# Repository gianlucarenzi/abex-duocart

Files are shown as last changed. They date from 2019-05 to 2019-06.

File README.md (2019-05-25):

Atari DUO Cart for ABEX
=====================

This is a Atari Duo Cart board, designed for the Atari PBI & ECI Bus EXtender
or ABEX for short.

This Atari DUO Cart is a derivated work of the famous Uno-Cart Project

Rendered Images
===============
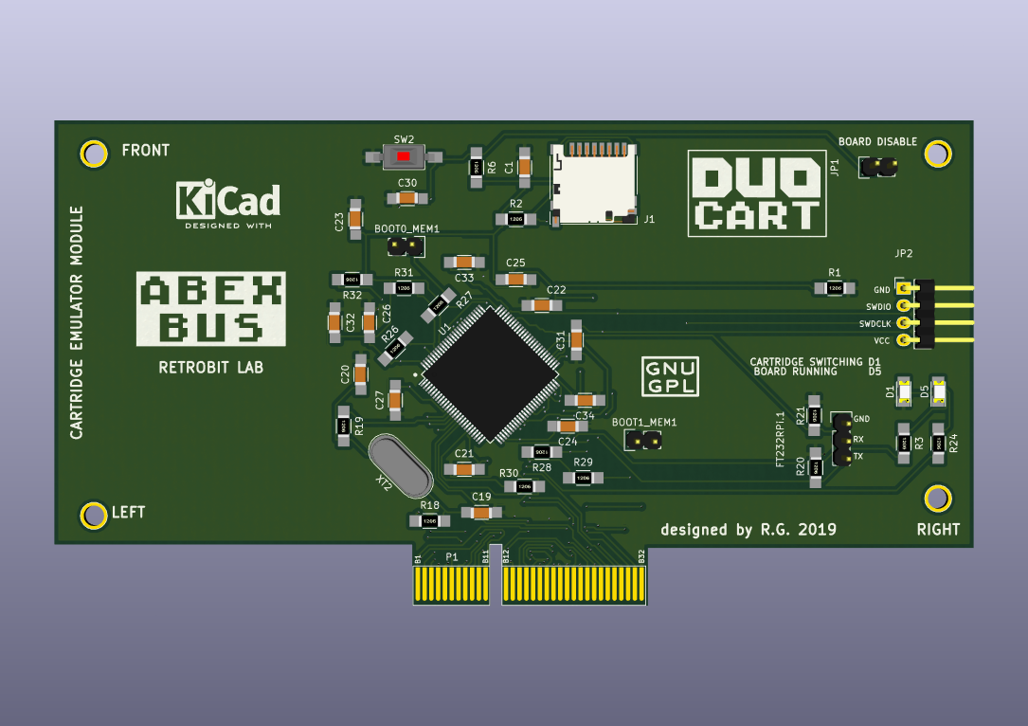
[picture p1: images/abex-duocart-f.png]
Board Front
# Front
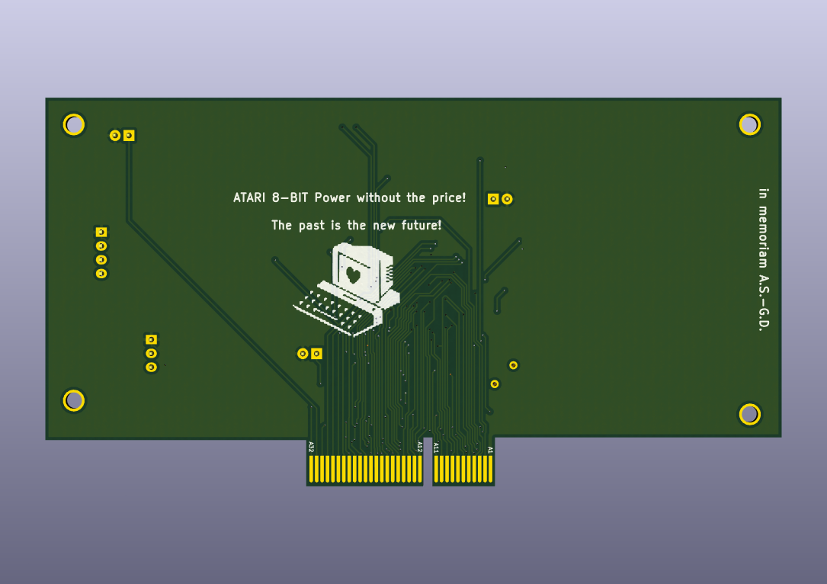
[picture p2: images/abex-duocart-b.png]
Board Back
# Back
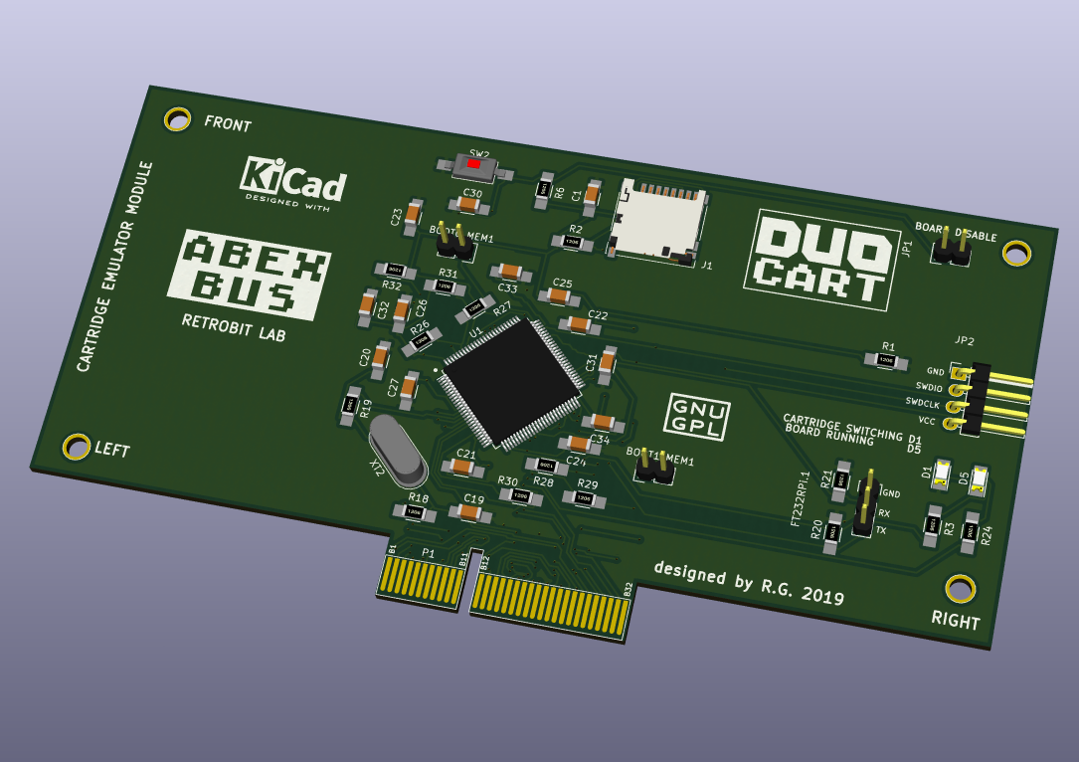
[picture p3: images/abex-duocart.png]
Board Overall
# Overall

Hardware License
================
Copyright (C) 2018/2019 Gianluca Renzi <gianlucarenzi@eurek.it> <icjtqr@gmail.com>

The hardware of this project is released as free/open hardware under the
Creative Commons Attribution Share-Alike license. See `LICENSE.hw` for details.

Firmware License
================
Copyright (C) 2019 Gianluca Renzi <icjtqr@gmail.com>

The microcontroller firmware of this project is released as free software,
under the terms of the GNU General Public License v3, or later.  See
`LICENSE.sw` for details.

Software License
================
The host software (amigafloppy tool) is released as free software, under the
terms of the GNU General Public License v3, or later. See `LICENSE.sw` or licence.txt for
details.

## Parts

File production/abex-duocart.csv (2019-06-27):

Id | Designator | Package | Quantity | Designation | Supplier and ref
1 | U1 | TQFP-100_14x14mm_Pitch0.5mm | 1 | STM32F407VGTx
2 | G*** | atari_800_XL_BW_25x25 | 1 | LOGO
3 | KICAD | KiCad-Logo2_6mm_SilkScreen | 1 | KiCad-Logo2_6mm_SilkScreen
4 | GPL | Symbol_GNU-GPL_SilkScreen_Small | 1 | Symbol_GNU-GPL_CopperTop_Small
5 | ATARI800XL | ABEX_Logo_22mmx11mm_WB | 1 | LOGO
6 | DUOCART | DUOCart_20x11_Rev | 1 | LOGO
7 | R24,R3 | R_1206_HandSoldering | 2 | 1.5K
8 | R2,R32,R31,R4,R5,R7 | R_1206_HandSoldering | 6 | 4.7K
9 | J1 | microSD_HC_Hirose_DM3D-SF | 1 | Micro_SD_Card_Det
10 | D5,D1 | LED_1206 | 2 | LED.GREEN
11 | C1,C31,C30,C27,C26,C25,C24,C23,C22,C21 | C_1206_HandSoldering | 10 | 100n
12 | P1 | BUS_PCIexpress_64pin | 1 | 0877159106
13 | XT2 | Crystal_HC49-4H_Vertical_3D | 1 | 8Mhz
14 | SW2 | SW_SPST_FSMSM_3D | 1 | SW_Push
15 | R30,R18,R1 | R_1206_HandSoldering | 3 | 0
16 | R29,R27 | R_1206_HandSoldering | 2 | 510
17 | R28,R26,R21,R20 | R_1206_HandSoldering | 4 | 10K
18 | R19 | R_1206_HandSoldering | 1 | 220
19 | R6 | R_1206_HandSoldering | 1 | 100K
20 | P5,P4,P3,P2 | MountingHole | 4 | CONN_01X01
21 | JP2 | Pin_Header_Angled_1x04 | 1 | CONN_01X04
22 | JP1,BOOT1_MEM1,BOOT0_MEM1 | Pin_Header_Straight_1x02 | 3 | CONN_01X02
23 | FT232RPi.1 | Pin_Header_Straight_1x03 | 1 | CONN_01X03
24 | C34,C33 | C_1206_HandSoldering | 2 | 2.2u
25 | C32 | C_1206_HandSoldering | 1 | 1u
26 | C20,C19 | C_1206_HandSoldering | 2 | 20p

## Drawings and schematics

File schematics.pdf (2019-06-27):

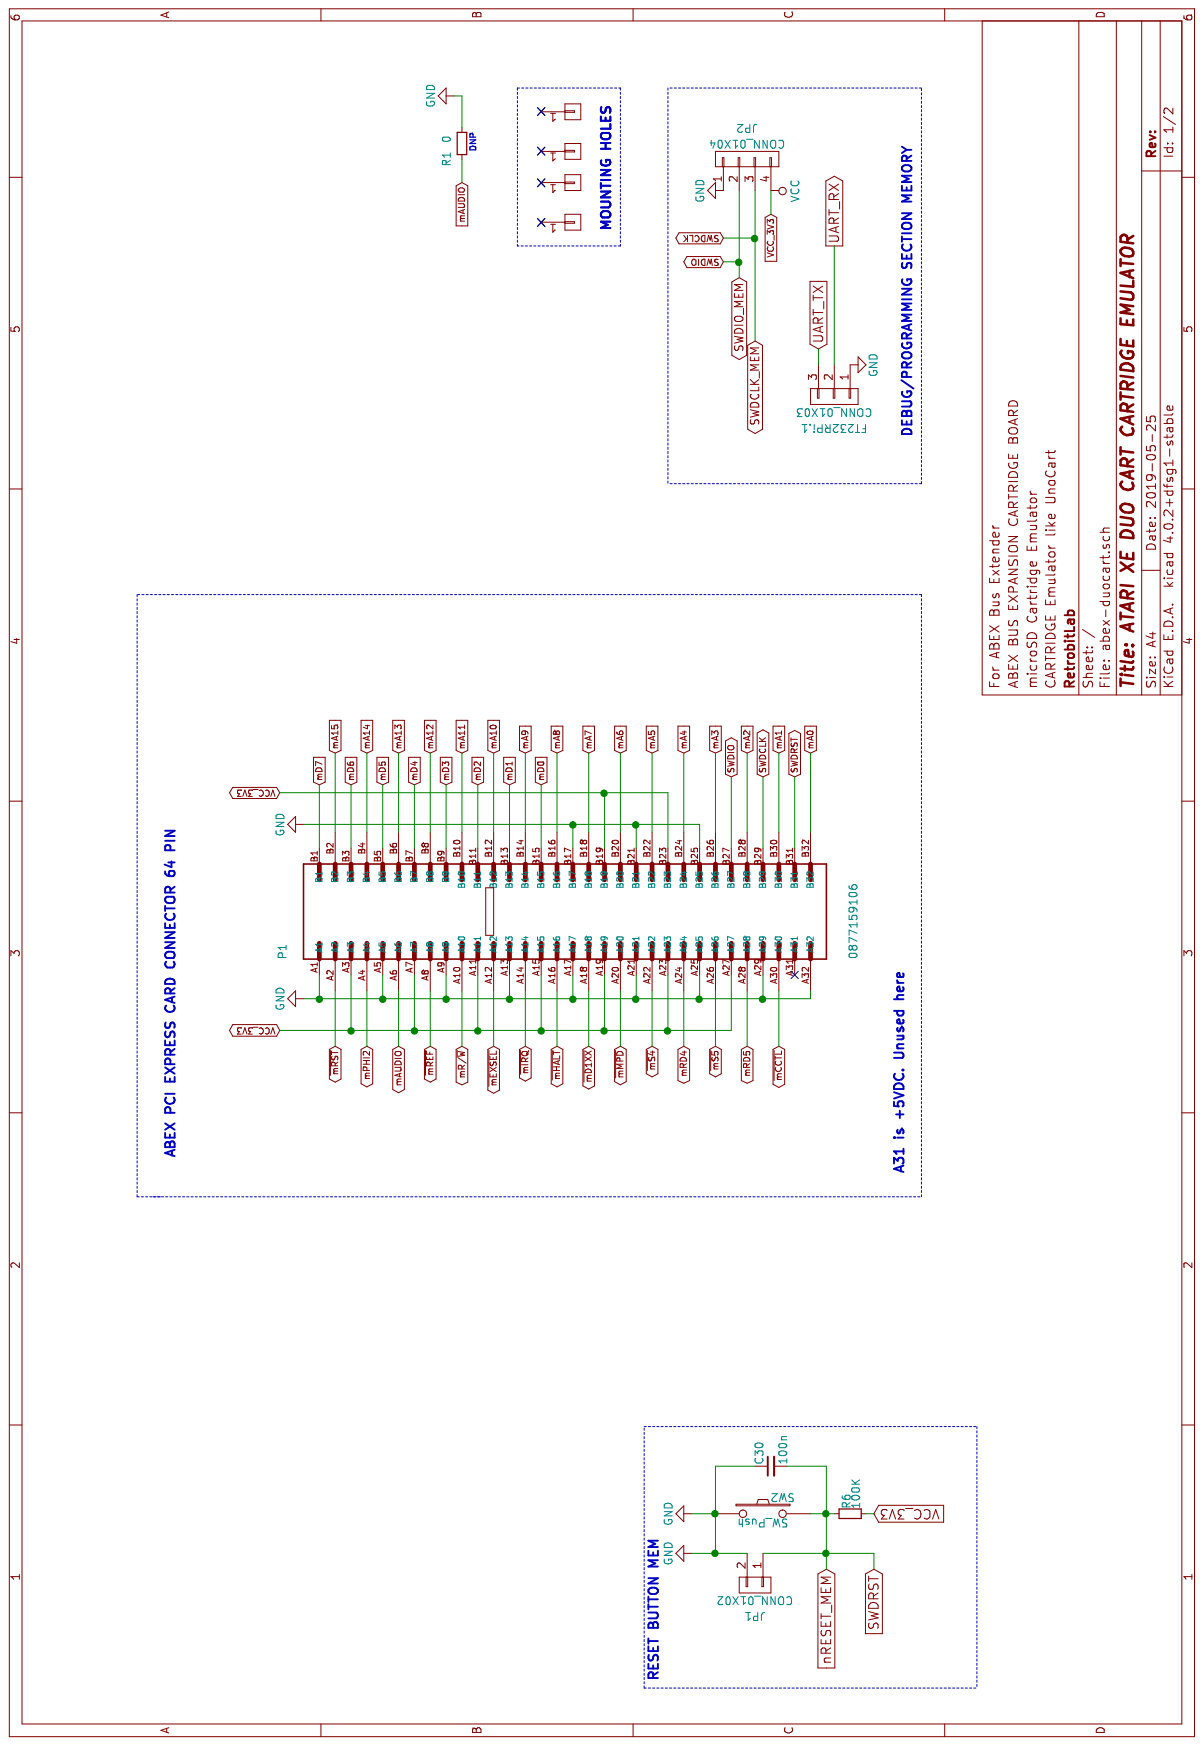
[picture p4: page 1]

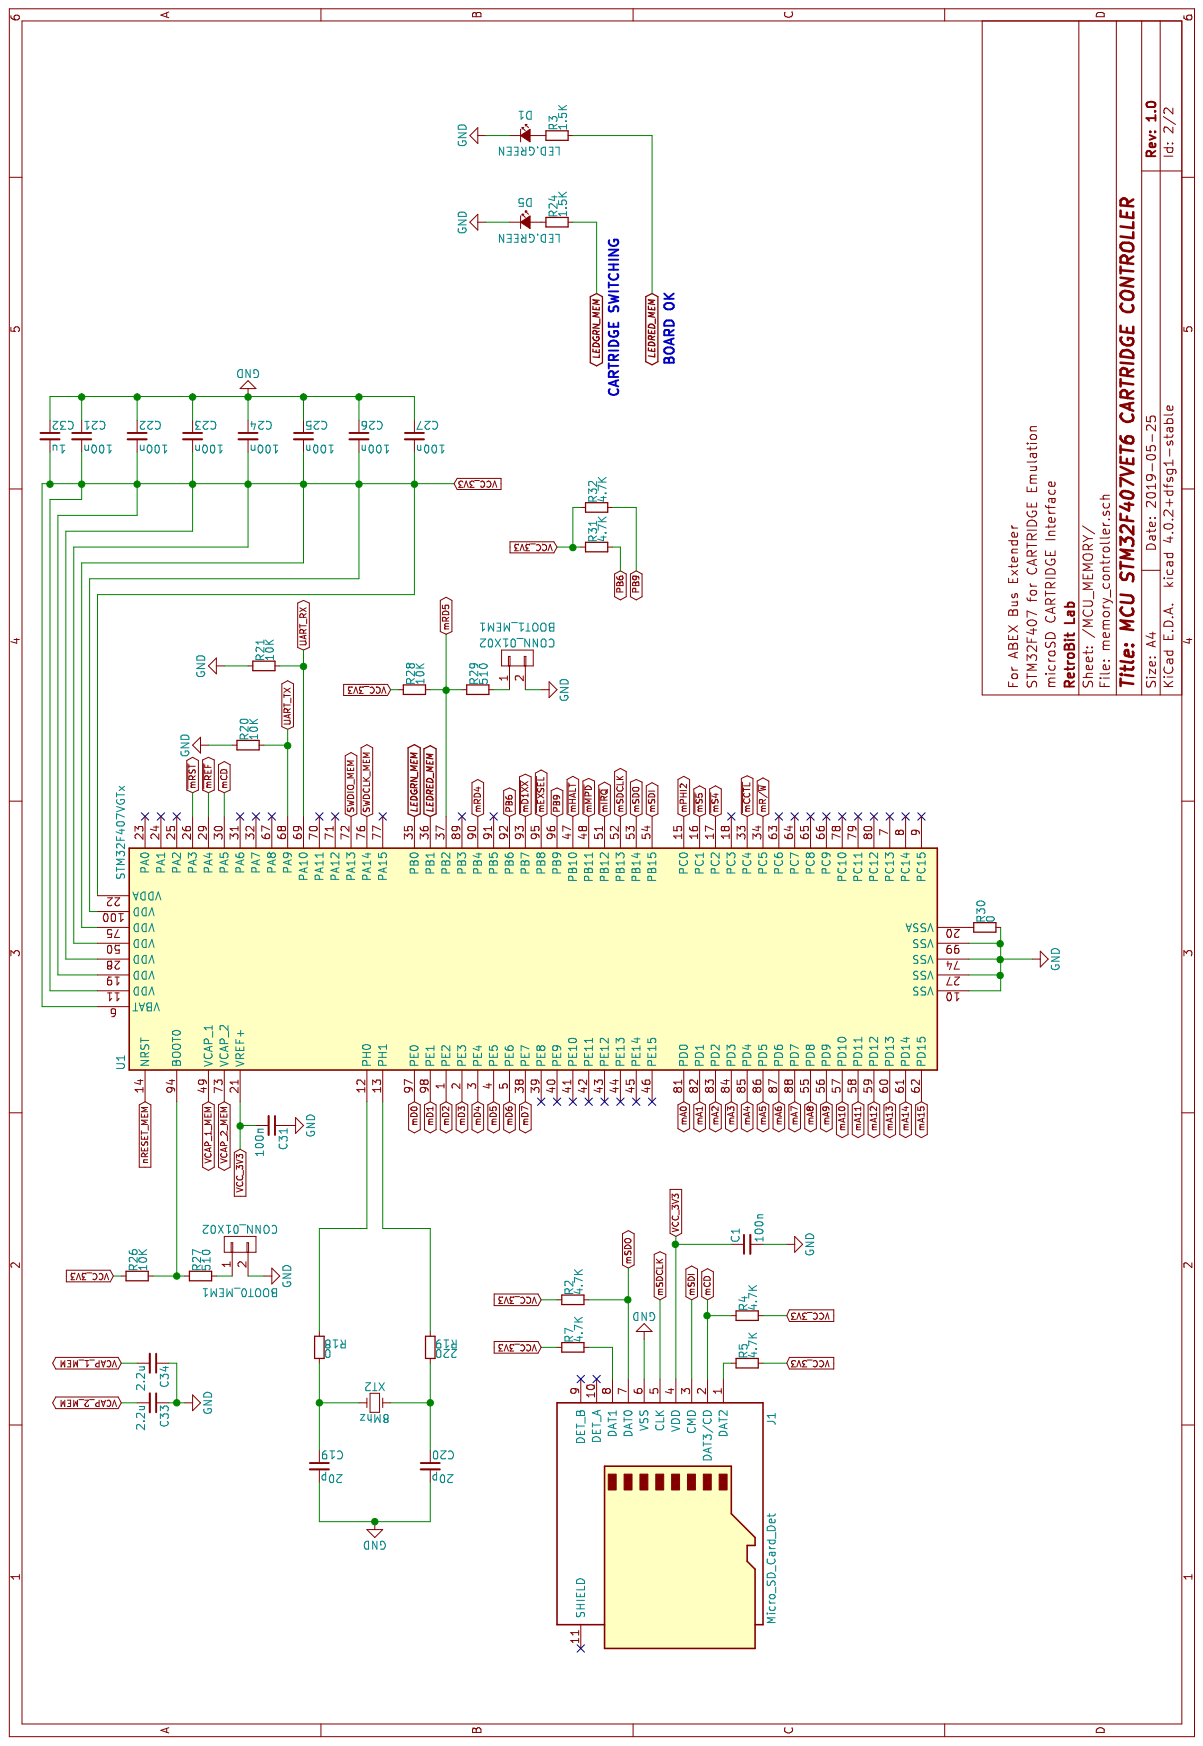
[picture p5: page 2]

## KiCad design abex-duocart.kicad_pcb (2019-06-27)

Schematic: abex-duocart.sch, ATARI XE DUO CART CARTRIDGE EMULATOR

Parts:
C30: 100n; C_1206_HandSoldering
FT232RPi.1: CONN_01X03; Pin_Header_Straight_1x03
JP1: CONN_01X02; Pin_Header_Straight_1x02
JP2: CONN_01X04; Pin_Header_Angled_1x04
P1: 0877159106; BUS_PCIexpress_64pin
P2, P3, P4, P5: CONN_01X01; MountingHole
R1: 0; R_1206_HandSoldering
R6: 100K; R_1206_HandSoldering
SW2: SW_Push; SW_SPST_FSMSM_3D

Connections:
GND: C30.1, FT232RPi.1.1, JP1.2, JP2.1, P1.A1, P1.A5, P1.A9, P1.A13, P1.A17, P1.A21, P1.A25, P1.A29, P1.A32, P1.B17, P1.B21, P1.B25, R1.2, SW2.1; also elsewhere on the board
SWDCLK: JP2.3, P1.B29; also elsewhere on the board
SWDIO: JP2.2, P1.B27; also elsewhere on the board
SWDRST: C30.2, JP1.1, P1.B31, R6.1, SW2.2; also elsewhere on the board
UART_RX: FT232RPi.1.2; also elsewhere on the board
UART_TX: FT232RPi.1.3; also elsewhere on the board
VCC_3V3: JP2.4, P1.A3, P1.A7, P1.A11, P1.A15, P1.A19, P1.A23, P1.A27, P1.B19, P1.B23, R6.2; also elsewhere on the board
mA0: P1.B32; also elsewhere on the board
mA1: P1.B30; also elsewhere on the board
mA2: P1.B28; also elsewhere on the board
mA3: P1.B26; also elsewhere on the board
mA4: P1.B24; also elsewhere on the board
mA5: P1.B22; also elsewhere on the board
mA6: P1.B20; also elsewhere on the board
mA7: P1.B18; also elsewhere on the board
mA8: P1.B16; also elsewhere on the board
mA9: P1.B14; also elsewhere on the board
mA10: P1.B12; also elsewhere on the board
mA11: P1.B10; also elsewhere on the board
mA12: P1.B8; also elsewhere on the board
mA13: P1.B6; also elsewhere on the board
mA14: P1.B4; also elsewhere on the board
mA15: P1.B2; also elsewhere on the board
mAUDIO: P1.A6, R1.1
mD0: P1.B15; also elsewhere on the board
mD1: P1.B13; also elsewhere on the board
mD2: P1.B11; also elsewhere on the board
mD3: P1.B9; also elsewhere on the board
mD4: P1.B7; also elsewhere on the board
mD5: P1.B5; also elsewhere on the board
mD6: P1.B3; also elsewhere on the board
mD7: P1.B1; also elsewhere on the board
mPHI2: P1.A4; also elsewhere on the board
mR/~W: P1.A10; also elsewhere on the board
mRD4: P1.A24; also elsewhere on the board
mRD5: P1.A28; also elsewhere on the board
~mCCTL: P1.A30; also elsewhere on the board
~mREF: P1.A8; also elsewhere on the board
~mRST: P1.A2; also elsewhere on the board
~mS4: P1.A22; also elsewhere on the board
~mS5: P1.A26; also elsewhere on the board

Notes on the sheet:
DEBUG/PROGRAMMING SECTION MEMORY
MOUNTING HOLES
RESET BUTTON MEM
DNP
ABEX PCI EXPRESS CARD CONNECTOR 64 PIN
A31 is +5VDC. Unused here

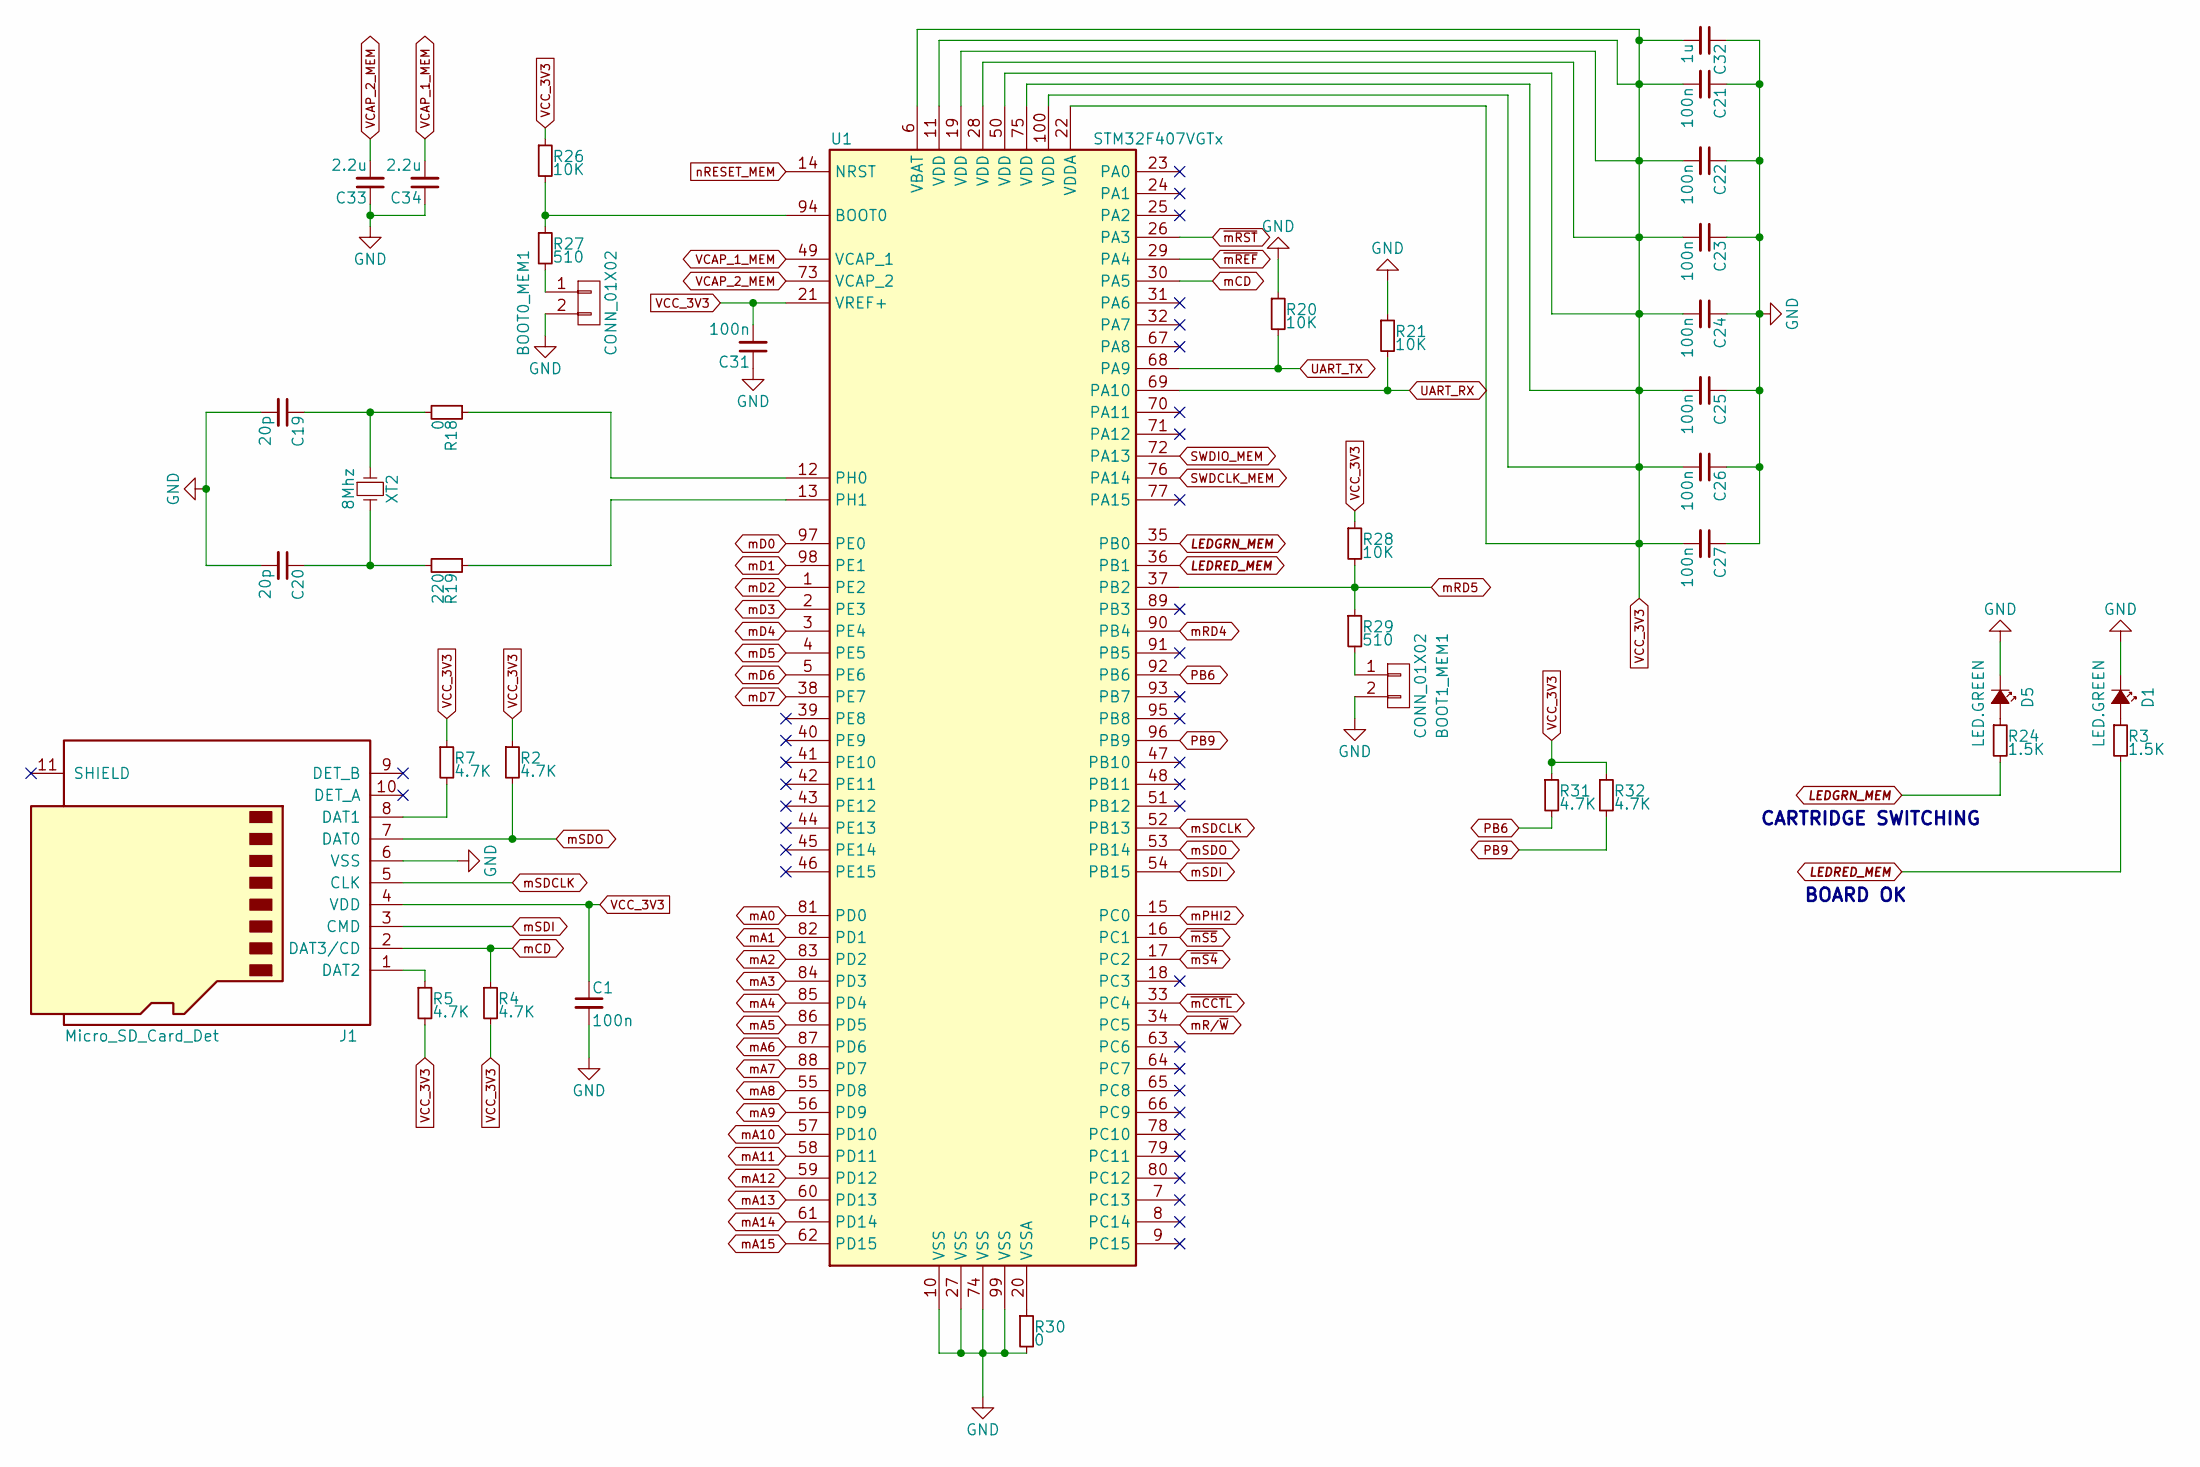
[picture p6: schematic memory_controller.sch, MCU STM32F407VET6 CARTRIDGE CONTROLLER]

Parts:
BOOT0_MEM1, BOOT1_MEM1: CONN_01X02; Pin_Header_Straight_1x02
C1, C21, C22, C23, C24, C25, C26, C27, C31: 100n; C_1206_HandSoldering
C19, C20: 20p; C_1206_HandSoldering
C32: 1u; C_1206_HandSoldering
C33, C34: 2.2u; C_1206_HandSoldering
D1, D5: LED.GREEN; LED_1206
J1: Micro_SD_Card_Det; microSD_HC_Hirose_DM3D-SF
R2, R4, R5, R7, R31, R32: 4.7K; R_1206_HandSoldering
R3, R24: 1.5K; R_1206_HandSoldering
R18, R30: 0; R_1206_HandSoldering
R19: 220; R_1206_HandSoldering
R20, R21, R26, R28: 10K; R_1206_HandSoldering
R27, R29: 510; R_1206_HandSoldering
U1: STM32F407VGTx; TQFP-100_14x14mm_Pitch0.5mm
XT2: 8Mhz; Crystal_HC49-4H_Vertical_3D

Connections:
GND: BOOT0_MEM1.2, BOOT1_MEM1.2, C1.2, C19.2, C20.2, C21.1, C22.1, C23.1, C24.1, C25.1, C26.1, C27.1, C31.1, C32.1, C33.1, C34.1, D1.1 (K), D5.1 (K), J1.6 (VSS), R20.1, R21.1, R30.2, U1.10 (VSS), U1.27 (VSS), U1.74 (VSS), U1.99 (VSS); also elsewhere on the board
LEDGRN_MEM: R24.2, U1.35 (PB0)
LEDRED_MEM: R3.2, U1.36 (PB1)
unnamed: BOOT0_MEM1.1, R27.2
unnamed: BOOT1_MEM1.1, R29.2
unnamed: C19.1, R18.2, XT2.1
unnamed: C20.1, R19.2, XT2.2
unnamed: D1.2 (A), R3.1
unnamed: D5.2 (A), R24.1
unnamed: J1.1 (DAT2), R5.1
unnamed: J1.8 (DAT1), R7.2
unnamed: R18.1, U1.12 (PH0)
unnamed: R19.1, U1.13 (PH1)
unnamed: R26.2, R27.1, U1.94 (BOOT0)
unnamed: R30.1, U1.20 (VSSA)
PB6: R31.2, U1.92 (PB6)
PB9: R32.2, U1.96 (PB9)
SWDCLK: U1.76 (PA14); also elsewhere on the board
SWDIO: U1.72 (PA13); also elsewhere on the board
SWDRST: U1.14 (NRST); also elsewhere on the board
UART_RX: R21.2, U1.69 (PA10); also elsewhere on the board
UART_TX: R20.2, U1.68 (PA9); also elsewhere on the board
VCAP_1_MEM: C34.2, U1.49 (VCAP_1)
VCAP_2_MEM: C33.2, U1.73 (VCAP_2)
VCC_3V3: C1.1, C21.2, C22.2, C23.2, C24.2, C25.2, C26.2, C27.2, C31.2, C32.2, J1.4 (VDD), R2.1, R4.2, R5.2, R7.1, R26.1, R28.1, R31.1, R32.1, U1.6 (VBAT), U1.11 (VDD), U1.19 (VDD), U1.21 (VREF+), U1.22 (VDDA), U1.28 (VDD), U1.50 (VDD), U1.75 (VDD), U1.100 (VDD); also elsewhere on the board
mA0: U1.81 (PD0); also elsewhere on the board
mA1: U1.82 (PD1); also elsewhere on the board
mA2: U1.83 (PD2); also elsewhere on the board
mA3: U1.84 (PD3); also elsewhere on the board
mA4: U1.85 (PD4); also elsewhere on the board
mA5: U1.86 (PD5); also elsewhere on the board
mA6: U1.87 (PD6); also elsewhere on the board
mA7: U1.88 (PD7); also elsewhere on the board
mA8: U1.55 (PD8); also elsewhere on the board
mA9: U1.56 (PD9); also elsewhere on the board
mA10: U1.57 (PD10); also elsewhere on the board
mA11: U1.58 (PD11); also elsewhere on the board
mA12: U1.59 (PD12); also elsewhere on the board
mA13: U1.60 (PD13); also elsewhere on the board
mA14: U1.61 (PD14); also elsewhere on the board
mA15: U1.62 (PD15); also elsewhere on the board
mCD: J1.2 (DAT3/CD), R4.1, U1.30 (PA5)
mD0: U1.97 (PE0); also elsewhere on the board
mD1: U1.98 (PE1); also elsewhere on the board
mD2: U1.1 (PE2); also elsewhere on the board
mD3: U1.2 (PE3); also elsewhere on the board
mD4: U1.3 (PE4); also elsewhere on the board
mD5: U1.4 (PE5); also elsewhere on the board
mD6: U1.5 (PE6); also elsewhere on the board
mD7: U1.38 (PE7); also elsewhere on the board
mPHI2: U1.15 (PC0); also elsewhere on the board
mR/~W: U1.34 (PC5); also elsewhere on the board
mRD4: U1.90 (PB4); also elsewhere on the board
mRD5: R28.2, R29.1, U1.37 (PB2); also elsewhere on the board
mSDCLK: J1.5 (CLK), U1.52 (PB13)
mSDI: J1.3 (CMD), U1.54 (PB15)
mSDO: J1.7 (DAT0), R2.2, U1.53 (PB14)
~mCCTL: U1.33 (PC4); also elsewhere on the board
~mREF: U1.29 (PA4); also elsewhere on the board
~mRST: U1.26 (PA3); also elsewhere on the board
~mS4: U1.17 (PC2); also elsewhere on the board
~mS5: U1.16 (PC1); also elsewhere on the board

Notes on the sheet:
CARTRIDGE SWITCHING
BOARD OK

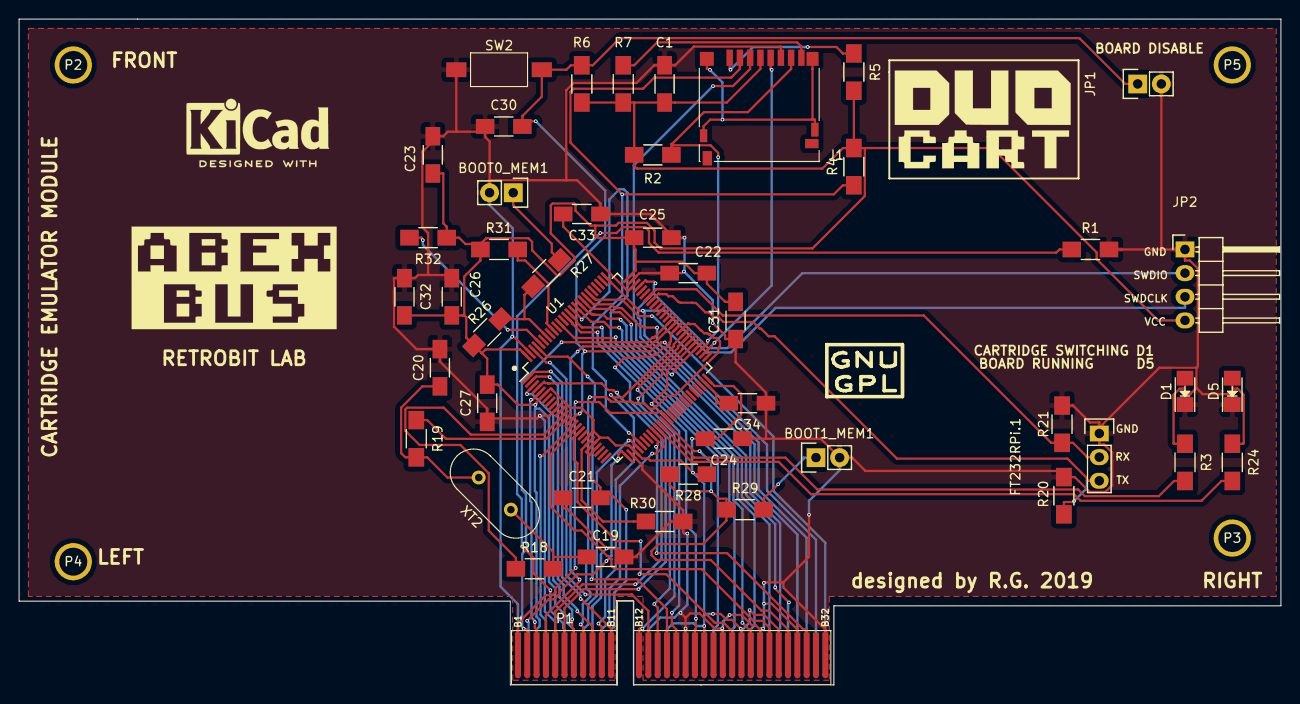
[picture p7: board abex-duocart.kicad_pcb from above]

Board: 2 copper layers, 135.5 x 71.5 mm, 54 parts (0 on the bottom side), 63 nets.

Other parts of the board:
ATARI800XL: LOGO; ABEX_Logo_22mmx11mm_WB
DUOCART: LOGO; DUOCart_20x11_Rev
GPL: Symbol_GNU-GPL_CopperTop_Small; Symbol_GNU-GPL_SilkScreen_Small
KICAD: KiCad-Logo2_6mm_SilkScreen

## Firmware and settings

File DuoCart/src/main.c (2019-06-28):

/*
 * ---------------------------------------
 * DUOCart Firmware (c)2019 Gianluca Renzi
 *
 * based on the original work by:
 *
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
 * You should have received a copy of the GNU General Public License
 * along with this program.  If not, see <http://www.gnu.org/licenses/>.
 */

#define _GNU_SOURCE

#include "defines.h"
#include "stm32f4xx.h"
#include "tm_stm32f4_fatfs.h"
#include "tm_stm32f4_delay.h"
#include <stdio.h>
#include <string.h>

#include "rom.h" /* unsigned char cart_rom[64*1024] */
#include "osrom.h"

#ifdef STM32F407xE
	#define stricmp strcasecmp
	#define strnicmp strncasecmp
#endif

static unsigned char cart_ram1[64*1024];
static unsigned char cart_ram2[64*1024] __attribute__((section(".ccmram")));
static unsigned char cart_d5xx[256] = {0};
static char errorBuf[40];

#define CART_CMD_OPEN_ITEM          0x00
#define CART_CMD_READ_CUR_DIR       0x01
#define CART_CMD_GET_DIR_ENTRY      0x02
#define CART_CMD_UP_DIR             0x03
#define CART_CMD_ROOT_DIR           0x04
#define CART_CMD_SEARCH             0x05
#define CART_CMD_LOAD_SOFT_OS       0x10
#define CART_CMD_SOFT_OS_CHUNK      0x11
#define CART_CMD_MOUNT_ATR          0x20    // unused, done automatically by firmware
#define CART_CMD_READ_ATR_SECTOR    0x21
#define CART_CMD_WRITE_ATR_SECTOR   0x22
#define CART_CMD_ATR_HEADER         0x23
#define CART_CMD_NO_CART            0xFE
#define CART_CMD_ACTIVATE_CART      0xFF

#define CART_TYPE_NONE              0
#define CART_TYPE_8K                1   // 8k
#define CART_TYPE_16K               2   // 16k
#define CART_TYPE_XEGS_32K          3   // 32k
#define CART_TYPE_XEGS_64K          4   // 64k
#define CART_TYPE_XEGS_128K         5   // 128k
#define CART_TYPE_SW_XEGS_32K       6   // 32k
#define CART_TYPE_SW_XEGS_64K       7   // 64k
#define CART_TYPE_SW_XEGS_128K      8   // 128k
#define CART_TYPE_MEGACART_16K      9   // 16k
#define CART_TYPE_MEGACART_32K      10  // 32k
#define CART_TYPE_MEGACART_64K      11  // 64k
#define CART_TYPE_MEGACART_128K     12  // 128k
#define CART_TYPE_BOUNTY_BOB        13  // 40k
#define CART_TYPE_ATARIMAX_1MBIT    14  // 128k
#define CART_TYPE_WILLIAMS_64K      15  // 32k/64k
#define CART_TYPE_OSS_16K_TYPE_B    16  // 16k
#define CART_TYPE_OSS_8K            17  // 8k
#define CART_TYPE_OSS_16K_034M      18  // 16k
#define CART_TYPE_OSS_16K_043M      19  // 16k
#define CART_TYPE_SIC_128K          20  // 128k
#define CART_TYPE_SDX_64K           21  // 64k
#define CART_TYPE_SDX_128K          22  // 128k
#define CART_TYPE_DIAMOND_64K       23  // 64k
#define CART_TYPE_EXPRESS_64K       24  // 64k
#define CART_TYPE_BLIZZARD_16K      25  // 16k
#define CART_TYPE_ATR               254
#define CART_TYPE_XEX               255

typedef struct {
	char isDir;
	char filename[13];
	char long_filename[32];
	char full_path[210];
} DIR_ENTRY;    // 256 bytes = 256 entries in 64k

static int num_dir_entries = 0; // how many entries in the current directory

static int entry_compare(const void* p1, const void* p2)
{
	DIR_ENTRY* e1 = (DIR_ENTRY*)p1;
	DIR_ENTRY* e2 = (DIR_ENTRY*)p2;
	if (e1->isDir && !e2->isDir)
		return -1;
	else
	if (!e1->isDir && e2->isDir)
		return 1;
	else
		return stricmp(e1->long_filename, e2->long_filename);
}

static char *get_filename_ext(char *filename)
{
	char *dot = strrchr(filename, '.');
	if(!dot || dot == filename)
		return "";
	return dot + 1;
}

static int is_valid_file(char *filename)
{
	char *ext = get_filename_ext(filename);
	if (stricmp(ext, "CAR") == 0 || stricmp(ext, "ROM") == 0
			|| stricmp(ext, "XEX") == 0 || stricmp(ext, "ATR") == 0)
		return 1;
	return 0;
}

// single FILINFO structure
static FILINFO fno;
static char lfn[_MAX_LFN + 1];   /* Buffer to store the LFN */

static void init()
{
	// this seems to be required for this version of FAT FS
	fno.lfname = lfn;
	fno.lfsize = sizeof lfn;
}

static int scan_files(char *path, char *search)
{
	FRESULT res;
	DIR dir;
	UINT i;

	res = f_opendir(&dir, path);
	if (res == FR_OK)
	{
		for (;;)
		{
			if (num_dir_entries == 255) break;
			res = f_readdir(&dir, &fno);
			if (res != FR_OK || fno.fname[0] == 0) break;
			if (fno.fattrib & (AM_HID | AM_SYS)) continue;
			if (fno.fattrib & AM_DIR)
			{
				i = strlen(path);
				strcat(path, "/");
				strcat(path, fno.fname);
				if (strlen(path) >= 210) continue;  // no more room for path in DIR_ENTRY
				res = scan_files(path, search);
				if (res != FR_OK) break;
				path[i] = 0;
			}
			else if (is_valid_file(fno.fname))
			{
				// copy the 8.3 filename to the LFN if blank
				if (!fno.lfname[0])
					strcpy(fno.lfname, fno.fname);
				char *match = strcasestr(fno.lfname, search);
				if (match)
				{
					DIR_ENTRY *dst = (DIR_ENTRY *)&cart_ram1[0];
					dst += num_dir_entries;
					// fill out a record
					dst->isDir = (match == fno.lfname) ? 1 : 0; // use this for a "score"
					strcpy(dst->filename, fno.fname);
					strncpy(dst->long_filename, fno.lfname, 31);
					dst->long_filename[31] = 0;
					// full path for search results
					strcpy(dst->full_path, path);
					num_dir_entries++;
				}
			}
		}
		f_closedir(&dir);
	}
	return res;
}

static int search_directory(char *path, char *search)
{
	char pathBuf[256];
	strcpy(pathBuf, path);
	num_dir_entries = 0;
	int i;
	FATFS FatFs;
	TM_DELAY_Init();
	if (f_mount(&FatFs, "", 1) == FR_OK)
	{
		if (scan_files(pathBuf, search) == FR_OK)
		{
			// sort by score, name
			qsort((DIR_ENTRY *)&cart_ram1[0], num_dir_entries, sizeof(DIR_ENTRY), entry_compare);
			DIR_ENTRY *dst = (DIR_ENTRY *)&cart_ram1[0];
			// reset the "scores" back to 0
			for (i=0; i<num_dir_entries; i++)
				dst[i].isDir = 0;
			return 1;
		}
	}
	strcpy(errorBuf, "Problem searching SD card");
	return 0;
}

static int read_directory(char *path)
{
	int ret = 0;
	num_dir_entries = 0;
	DIR_ENTRY *dst = (DIR_ENTRY *)&cart_ram1[0];

	FATFS FatFs;
	TM_DELAY_Init();
	if (f_mount(&FatFs, "", 1) == FR_OK)
	{
		DIR dir;
		if (f_opendir(&dir, path) == FR_OK)
		{
			while (num_dir_entries < 255)
			{
				if (f_readdir(&dir, &fno) != FR_OK || fno.fname[0] == 0)
					break;
				if (fno.fattrib & (AM_HID | AM_SYS))
					continue;
				dst->isDir = fno.fattrib & AM_DIR ? 1 : 0;
				if (!dst->isDir)
				{
					if (!is_valid_file(fno.fname))
						continue;
				}
				// copy file record to first ram block
				strcpy(dst->filename, fno.fname);
				if (fno.lfname[0])
				{
					strncpy(dst->long_filename, fno.lfname, 31);
					dst->long_filename[31] = 0;
				}
				else
				{
					strcpy(dst->long_filename, fno.fname);
				}
				dst->full_path[0] = 0; // path only for search results
				dst++;
				num_dir_entries++;
			}
			f_closedir(&dir);
		}
		else
		{
			strcpy(errorBuf, "Can't read directory");
		}
		f_mount(0, "", 1);
		qsort((DIR_ENTRY *)&cart_ram1[0], num_dir_entries, sizeof(DIR_ENTRY), entry_compare);
		ret = 1;
	}
	else
	{
		strcpy(errorBuf, "Can't read SD card");
	}
	return ret;
}

/* ATR Handling */

// ATR format
#define ATR_HEADER_SIZE 16
#define ATR_SIGNATURE 0x0296
typedef struct {
	uint16_t signature;
	uint16_t pars;
	uint16_t secSize;
	uint16_t parsHigh;
	uint8_t flags;
	uint16_t protInfo;
	uint8_t unused[5];
} ATRHeader;

typedef struct {
	char path[256];
	ATRHeader atrHeader;
	int filesize;
	FIL fil;
} MountedATR;

static MountedATR mountedATRs[1] = {0};

static FATFS FatFs;
static int doneFatFsInit = 0;

static int mount_atr(char *filename)
{
	// returns 0 for success or error code
	// 1 = no media, 2 = no file, 3 = bad atr
	if (!doneFatFsInit)
	{
		if (f_mount(&FatFs, "", 1) != FR_OK)
			return 1;
		doneFatFsInit = 1;
	}

	MountedATR *mountedATR = &mountedATRs[0];
	if (f_open(&mountedATR->fil, filename, FA_READ|FA_WRITE) != FR_OK)
		return 2;

	UINT br;
	if (f_read(&mountedATR->fil, &mountedATR->atrHeader, ATR_HEADER_SIZE, &br) != FR_OK ||
		br != ATR_HEADER_SIZE || mountedATR->atrHeader.signature != ATR_SIGNATURE)
	{
		f_close(&mountedATR->fil);
		return 3;
	}
	// success
	strcpy(mountedATR->path, filename);
	mountedATR->filesize = f_size(&mountedATR->fil);
	return 0;
}

static int read_atr_sector(uint16_t sector, uint8_t page, uint8_t *buf)
{
	// returns 0 for success or error code
	// 1 = no ATR mounted, 2 = invalid sector
	MountedATR *mountedATR = &mountedATRs[0];

	if (!mountedATR->path[0])
		return 1;

	if (sector == 0)
		return 2;

	int offset = ATR_HEADER_SIZE;
	// first 3 sectors are always 128 bytes
	if (sector <=3)
		offset += (sector - 1) * 128;
	else
		offset += (3 * 128) + ((sector - 4) * mountedATR->atrHeader.secSize) + (page * 128);

	// check we're not reading beyond the end of the file..
	if (offset > (mountedATR->filesize - 128))
	{
		memset(buf, 0 , 128);   // return blank sector?
		return 0;
	}

	UINT br;
	if (f_lseek(&mountedATR->fil, offset) != FR_OK ||
		f_read(&mountedATR->fil, buf, 128, &br) != FR_OK || br != 128)
		return 2;
	return 0;
}

static int write_atr_sector(uint16_t sector, uint8_t page, uint8_t *buf)
{
	// returns 0 for success or error code
	// 1 = no ATR mounted, 2 = write error
	MountedATR *mountedATR = &mountedATRs[0];

	if (!mountedATR->path[0])
		return 1;

	if (sector == 0)
		return 2;

	int offset = ATR_HEADER_SIZE;
	// first 3 sectors are always 128 bytes
	if (sector <=3)
		offset += (sector - 1) * 128;
	else
		offset += (3 * 128) + ((sector - 4) * mountedATR->atrHeader.secSize) + (page * 128);

	// check we're not writing beyond the end of the file..
	if (offset > (mountedATR->filesize - 128))
		return 2;
	UINT bw;
	if (f_lseek(&mountedATR->fil, offset) != FR_OK ||
		f_write(&mountedATR->fil, buf, 128, &bw) != FR_OK ||
		f_sync(&mountedATR->fil) != FR_OK  || bw != 128)
		return 2;
	return 0;
}

/* CARTRIDGE/XEX HANDLING */

static int load_file(char *filename)
{
	TM_DELAY_Init();
	FATFS FatFs;
	int cart_type = CART_TYPE_NONE;
	int car_file = 0, xex_file = 0, expectedSize = 0;
	unsigned char carFileHeader[16];
	UINT br, size = 0;

	if (strncasecmp(filename+strlen(filename)-4, ".CAR", 4) == 0)
		car_file = 1;
	if (strncasecmp(filename+strlen(filename)-4, ".XEX", 4) == 0)
		xex_file = 1;

	if (f_mount(&FatFs, "", 1) != FR_OK)
	{
		strcpy(errorBuf, "Can't read SD card");
		return 0;
	}

	FIL fil;
	if (f_open(&fil, filename, FA_READ) != FR_OK)
	{
		strcpy(errorBuf, "Can't open file");
		goto cleanup;
	}

	// read the .CAR file header?
	if (car_file)
	{
		if (f_read(&fil, carFileHeader, 16, &br) != FR_OK || br != 16)
		{
			strcpy(errorBuf, "Bad CAR file");
			goto closefile;
		}

		int car_type = carFileHeader[7];
		if (car_type == 1)       { cart_type = CART_TYPE_8K;             expectedSize =   8192; }
		else if (car_type == 2)  { cart_type = CART_TYPE_16K;            expectedSize =  16384; }
		else if (car_type == 3)  { cart_type = CART_TYPE_OSS_16K_034M;   expectedSize =  16384; }
		else if (car_type == 8)  { cart_type = CART_TYPE_WILLIAMS_64K;   expectedSize =  65536; }
		else if (car_type == 9)  { cart_type = CART_TYPE_EXPRESS_64K;    expectedSize =  65536; }
		else if (car_type == 10) { cart_type = CART_TYPE_DIAMOND_64K;    expectedSize =  65536; }
		else if (car_type == 11) { cart_type = CART_TYPE_SDX_64K;        expectedSize =  65536; }
		else if (car_type == 12) { cart_type = CART_TYPE_XEGS_32K;       expectedSize =  32768; }
		else if (car_type == 13) { cart_type = CART_TYPE_XEGS_64K;       expectedSize =  65536; }
		else if (car_type == 14) { cart_type = CART_TYPE_XEGS_128K;      expectedSize = 131072; }
		else if (car_type == 15) { cart_type = CART_TYPE_OSS_16K_TYPE_B; expectedSize =  16384; }
		else if (car_type == 18) { cart_type = CART_TYPE_BOUNTY_BOB;     expectedSize =  40960; }
		else if (car_type == 22) { cart_type = CART_TYPE_WILLIAMS_64K;   expectedSize =  32768; }
		else if (car_type == 26) { cart_type = CART_TYPE_MEGACART_16K;   expectedSize =  16384; }
		else if (car_type == 27) { cart_type = CART_TYPE_MEGACART_32K;   expectedSize =  32768; }
		else if (car_type == 28) { cart_type = CART_TYPE_MEGACART_64K;   expectedSize =  65536; }
		else if (car_type == 29) { cart_type = CART_TYPE_MEGACART_128K;  expectedSize = 131072; }
		else if (car_type == 33) { cart_type = CART_TYPE_SW_XEGS_32K;    expectedSize =  32768; }
		else if (car_type == 34) { cart_type = CART_TYPE_SW_XEGS_64K;    expectedSize =  65536; }
		else if (car_type == 35) { cart_type = CART_TYPE_SW_XEGS_128K;   expectedSize = 131072; }
		else if (car_type == 40) { cart_type = CART_TYPE_BLIZZARD_16K;   expectedSize =  16384; }
		else if (car_type == 41) { cart_type = CART_TYPE_ATARIMAX_1MBIT; expectedSize = 131072; }
		else if (car_type == 43) { cart_type = CART_TYPE_SDX_128K;       expectedSize = 131072; }
		else if (car_type == 44) { cart_type = CART_TYPE_OSS_8K;         expectedSize =   8192; }
		else if (car_type == 45) { cart_type = CART_TYPE_OSS_16K_043M;   expectedSize =  16384; }
		else if (car_type == 54) { cart_type = CART_TYPE_SIC_128K;       expectedSize = 131072; }
		else
		{
			strcpy(errorBuf, "Unsupported CAR type");
			goto closefile;
		}
	}

	// set a default error
	strcpy(errorBuf, "Can't read file");

	unsigned char *dst = &cart_ram1[0];
	int bytes_to_read = 64 * 1024;
	if (xex_file)
	{
		dst += 4;   // leave room for the file length at the start of sram
		bytes_to_read -= 4;
	}

	// read the file in two 64k chunks to each area of SRAM
	if (f_read(&fil, dst, bytes_to_read, &br) != FR_OK)
	{
		cart_type = CART_TYPE_NONE;
		goto closefile;
	}
	size += br;

	if (br == bytes_to_read)
	{
		// first 64k was complete, so try to load 64k more
		if (f_read(&fil, &cart_ram2[0], 64*1024, &br) != FR_OK)
		{
			cart_type = CART_TYPE_NONE;
			goto closefile;
		}
		size += br;
		if (br == 64*1024)
		{
			// that's 128k read, is there any more?
			if (f_read(&fil, carFileHeader, 1, &br) != FR_OK)
			{
				cart_type = CART_TYPE_NONE;
				goto closefile;
			}
			if  (br == 1)
			{
				strcpy(errorBuf, "Cart file/XEX too big (>128k)");
				cart_type = CART_TYPE_NONE;
				goto closefile;
			}
		}
	}

	// set the correct cart type based on the size
	if (car_file)
	{
		if (size != expectedSize)
		{
			strcpy(errorBuf, "CAR file is wrong size");
			cart_type = CART_TYPE_NONE;
			goto closefile;
		}
	}
	else if (xex_file)
	{
		cart_type = CART_TYPE_XEX;
		// stick the size of the file as the first 4 bytes (little endian)
		cart_ram1[0] = size & 0xFF;
		cart_ram1[1] = (size >> 8) & 0xFF;
		cart_ram1[2] = (size >> 16) & 0xFF;
		cart_ram1[3] = 0;   // has to be zero!
	}
	else
	{
		// not a car/xex file - guess the type based on size
		if (size == 8*1024)        cart_type = CART_TYPE_8K;
		else if (size == 16*1024)  cart_type = CART_TYPE_16K;
		else if (size == 32*1024)  cart_type = CART_TYPE_XEGS_32K;
		else if (size == 64*1024)  cart_type = CART_TYPE_XEGS_64K;
		else if (size == 128*1024) cart_type = CART_TYPE_XEGS_128K;
		else
		{
			strcpy(errorBuf, "Unsupported ROM size ");
			cart_type = CART_TYPE_NONE;
			goto closefile;
		}
	}

closefile:
	f_close(&fil);
cleanup:
	f_mount(0, "", 1);
	return cart_type;
}

#define RD5_LOW      GPIOB->BSRRH = GPIO_Pin_2;
#define RD4_LOW      GPIOB->BSRRH = GPIO_Pin_4;
#define RD5_HIGH     GPIOB->BSRRL = GPIO_Pin_2;
#define RD4_HIGH     GPIOB->BSRRL = GPIO_Pin_4;

#define CONTROL_IN   GPIOC->IDR
#define ADDR_IN      GPIOD->IDR
#define DATA_IN      GPIOE->IDR
#define DATA_OUT     GPIOE->ODR

#define PHI2_RD          (GPIOC->IDR & 0x0001)
#define S5_RD            (GPIOC->IDR & 0x0002)
#define S4_RD            (GPIOC->IDR & 0x0004)
#define S4_AND_S5_HIGH   (GPIOC->IDR & 0x0006) == 0x6

#define PHI2    0x0001
#define S5      0x0002
#define S4      0x0004
#define CCTL    0x0010
#define RW      0x0020

#define SET_DATA_MODE_IN      GPIOE->MODER = 0x00000000;
#define SET_DATA_MODE_OUT     GPIOE->MODER = 0x00005555;

#define GREEN_LED_OFF         GPIOB->BSRRH = GPIO_Pin_0;
#define RED_LED_OFF           GPIOB->BSRRH = GPIO_Pin_1;
#define GREEN_LED_ON          GPIOB->BSRRL = GPIO_Pin_0;
#define RED_LED_ON            GPIOB->BSRRL = GPIO_Pin_1;

#define ATARI_RESET_ASSERT    GPIOA->BSRRL = GPIO_Pin_3; /* RST -> GPIO(A.3) LOW */
#define ATARI_RESET_DEASSERT  GPIOA->BSRRH = GPIO_Pin_3; /* RST -> GPIO(A.3) HIGH */

enum {
    INSERTED = 0,
    REMOVED,
};

/* Polling CARD_STATUS will returns any NON-ZERO value if there is
 * NO CARD in the microSD Slot, otherwise it will returns '0' if a card
 * is inserted.
 */
#define CARD_STATUS    (GPIOA->IDR & (1 << 5))

/*
 * ******************** DEBUG PORT UART *****************************
 */
#define DEBUG_TX           GPIO_Pin_9
#define DEBUG_RX           GPIO_Pin_10
#define DEBUG_PINSRC_TX    GPIO_PinSource9
#define DEBUG_PINSRC_RX    GPIO_PinSource10
#define DEBUG_PORT         GPIOA
enum {
	DBG_ERROR = 0,
	DBG_INFO,
	DBG_VERBOSE,
	DBG_NOISY,
};
static int debuglevel = DBG_INFO;
#define print(str)  USART_PutString(str)
/* ANSI Eye-Candy ;-) */
#define ANSI_RED    "\x1b[31m"
#define ANSI_GREEN  "\x1b[32m"
#define ANSI_YELLOW "\x1b[1;33m"
#define ANSI_BLUE   "\x1b[1;34m"
#define ANSI_RESET  "\x1b[0m"
#define DBG_E(str)  print(ANSI_RED); print(str); print(ANSI_RESET);
#define DBG_I(str)  if (debuglevel >= DBG_INFO)    { print(ANSI_GREEN);  print(str); print(ANSI_RESET); }
#define DBG_V(str)  if (debuglevel >= DBG_VERBOSE) { print(ANSI_BLUE);   print(str); print(ANSI_RESET); }
#define DBG_N(str)  if (debuglevel >= DBG_NOISY)   { print(ANSI_YELLOW); print(str); print(ANSI_RESET); }

GPIO_InitTypeDef  GPIO_InitStructure;
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
int main(void)
{
	/* Output: RESET & REF */
	config_gpio_others();

	ATARI_RESET_ASSERT

	config_uart(115200);

	banner();

	DBG_V("ATARI COMPUTER IN RESET MODE\r\n");

	/* Ouptut: LEDS - PB{0..1}, RD5 - PB2, RD4 - PB4 */
	config_gpio_leds_RD45();
	/* InOut: Data - PE{8..15} */
	config_gpio_data();
	/* In: Address - PD{0..15} */
	config_gpio_addr();
	/* In: Other Cart Input Sigs - PC{0..2, 4..5} */
	config_gpio_sig();

	RED_LED_ON
	int cartType = 0, atrMode = 0;
	char curPath[256] = "";
	char path[256];
	init();

	DBG_V("ATARI COMPUTER OUT OF RESET MODE\r\n");

	ATARI_RESET_DEASSERT

	while (1)
	{
		GREEN_LED_OFF

		int cmd = emulate_boot_rom(atrMode);

		GREEN_LED_ON

		// OPEN ITEM n
		if (cmd == CART_CMD_OPEN_ITEM)
		{
			int n = cart_d5xx[0x00];
			DIR_ENTRY *entry = (DIR_ENTRY *)&cart_ram1[0];
			if (entry[n].isDir)
			{
				// directory
				strcat(curPath, "/");
				strcat(curPath, entry[n].filename);
				cart_d5xx[0x01] = 0; // path changed
			}
			else
			{
				// file/search result
				if (entry[n].full_path[0])
					strcpy(path, entry[n].full_path);   // search result
				else
					strcpy(path, curPath); // file in current directory

				strcat(path, "/");
				strcat(path, entry[n].filename);
				if (stricmp(get_filename_ext(entry[n].filename), "ATR")==0)
				{
					// ATR
					cart_d5xx[0x01] = 3;    // ATR
					cartType = CART_TYPE_ATR;
				}
				else
				{
					// ROM,CAR or XEX
					cartType = load_file(path);
					if (cartType)
						cart_d5xx[0x01] = (cartType != CART_TYPE_XEX ? 1 : 2);  // file was loaded
					else
					{
						cart_d5xx[0x01] = 4;    // error
						strcpy((char*)&cart_d5xx[0x02], errorBuf);
					}
				}
			}
		}
		// READ DIR
		else
		if (cmd == CART_CMD_READ_CUR_DIR)
		{
			int ret = read_directory(curPath);
			if (ret)
			{
				cart_d5xx[0x01] = 0;    // ok
				cart_d5xx[0x02] = num_dir_entries;
			}
			else
			{
				cart_d5xx[0x01] = 1;    // error
				strcpy((char*)&cart_d5xx[0x02], errorBuf);
			}
		}
		// GET DIR ENTRY n
		else
		if (cmd == CART_CMD_GET_DIR_ENTRY)
		{
			int n = cart_d5xx[0x00];
			DIR_ENTRY *entry = (DIR_ENTRY *)&cart_ram1[0];
			cart_d5xx[0x01] = entry[n].isDir;
			strcpy((char*)&cart_d5xx[0x02], entry[n].long_filename);
		}
		// UP A DIRECTORY LEVEL
		else
		if (cmd == CART_CMD_UP_DIR)
		{
			int len = strlen(curPath);
			while (len && curPath[--len] != '/')
				;
			curPath[len] = 0;
		}
		// ROOT DIR (when atari reset pressed)
		else
		if (cmd == CART_CMD_ROOT_DIR)
			curPath[0] = 0;
		// SEARCH str
		else
		if (cmd == CART_CMD_SEARCH)
		{
			char searchStr[32];
			strcpy(searchStr, (char*)&cart_d5xx[0x00]);
			int ret = search_directory(curPath, searchStr);
			if (ret)
			{
				cart_d5xx[0x01] = 0;    // ok
				cart_d5xx[0x02] = num_dir_entries;
			}
			else
			{
				cart_d5xx[0x01] = 1;    // error
				strcpy((char*)&cart_d5xx[0x02], errorBuf);
			}
		}
		else
		if (cmd == CART_CMD_LOAD_SOFT_OS)
		{
			int ret = load_file("UNO_OS.ROM");
			if (!ret)
			{
				for (int i=0; i<16384; i++)
					cart_ram1[i] = os_rom[i];
			}
			cart_d5xx[0x01] = 0;    // ok
		}
		else
		if (cmd == CART_CMD_SOFT_OS_CHUNK)
		{
			int n = cart_d5xx[0x00];
			for (int i=0; i<128; i++)
				cart_d5xx[0x01+i]=cart_ram1[n*128+i];
		}
		else
		if (cmd == CART_CMD_READ_ATR_SECTOR)
		{
			//uint8_t device = cart_d5xx[0x00];
			uint16_t sector = (cart_d5xx[0x02] << 8) | cart_d5xx[0x01];
			uint8_t offset = cart_d5xx[0x03];   // 0 = first 128 byte "page", 1 = second, etc
			int ret = read_atr_sector(sector, offset, &cart_d5xx[0x02]);
			cart_d5xx[0x01] = ret;
		}
		else
		if (cmd == CART_CMD_WRITE_ATR_SECTOR)
		{
			//uint8_t device = cart_d5xx[0x00];
			GREEN_LED_OFF
			RED_LED_ON
			uint16_t sector = (cart_d5xx[0x02] << 8) | cart_d5xx[0x01];
			uint8_t offset = cart_d5xx[0x03];   // 0 = first 128 byte "page", 1 = second, etc
			int ret = write_atr_sector(sector, offset, &cart_d5xx[0x04]);
			cart_d5xx[0x01] = ret;
			RED_LED_OFF
		}
		else
		if (cmd == CART_CMD_ATR_HEADER)
		{
			//uint8_t device = cart_d5xx[0x00];
			if (!&mountedATRs[0].path[0])
				cart_d5xx[0x01] = 1;
			else
			{
				memcpy(&cart_d5xx[0x02], &mountedATRs[0].atrHeader, 16);
				cart_d5xx[0x01] = 0;
			}
		}
		// NO CART
		else
		if (cmd == CART_CMD_NO_CART)
			cartType = 0;
		// REBOOT TO CART
		else
		if (cmd == CART_CMD_ACTIVATE_CART)
		{
			if (cartType == CART_TYPE_ATR)
			{
				atrMode = 1;
				RED_LED_OFF
				int ret = mount_atr(path);
				if (ret == 0)
					memcpy(&cart_d5xx[0x02], &mountedATRs[0].atrHeader, 16);
				cart_d5xx[0x01] = ret;
			}
			else
				emulate_cartridge(cartType);
		}
	}
}

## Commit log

2019-06-02 Corrected some silkscreen bugs
    [abex-duocart-B.Cu.gbl, abex-duocart-B.Mask.gbs, abex-duocart-B.Paste.gbp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]
2019-06-27 Added the CardDetect. Added the A31 +5V pin
    [abex-duocart-B.Cu.gbl, abex-duocart-B.Mask.gbs, abex-duocart-B.Paste.gbp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]
2025-11-01 RetroBitLab library
    [abex-duocart.sch, memory_controller.sch]

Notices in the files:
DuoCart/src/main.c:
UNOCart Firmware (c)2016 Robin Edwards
